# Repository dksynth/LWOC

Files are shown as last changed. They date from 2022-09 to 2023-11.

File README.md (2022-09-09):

# LWOC
Ornament and Crime for Loudest Warning Format

please note that there are two different spacings in use. 

The "broken grid" variant pushes two rows a bit closer together towards the screen at the bottom. This preserves the spacing of the top row at the cost of a crowded set of jacks nearer the encoders and  screen. 

IN ALMOST ALL CASES (unless you've made your own panels) you will want to use the main files found in the main repository.

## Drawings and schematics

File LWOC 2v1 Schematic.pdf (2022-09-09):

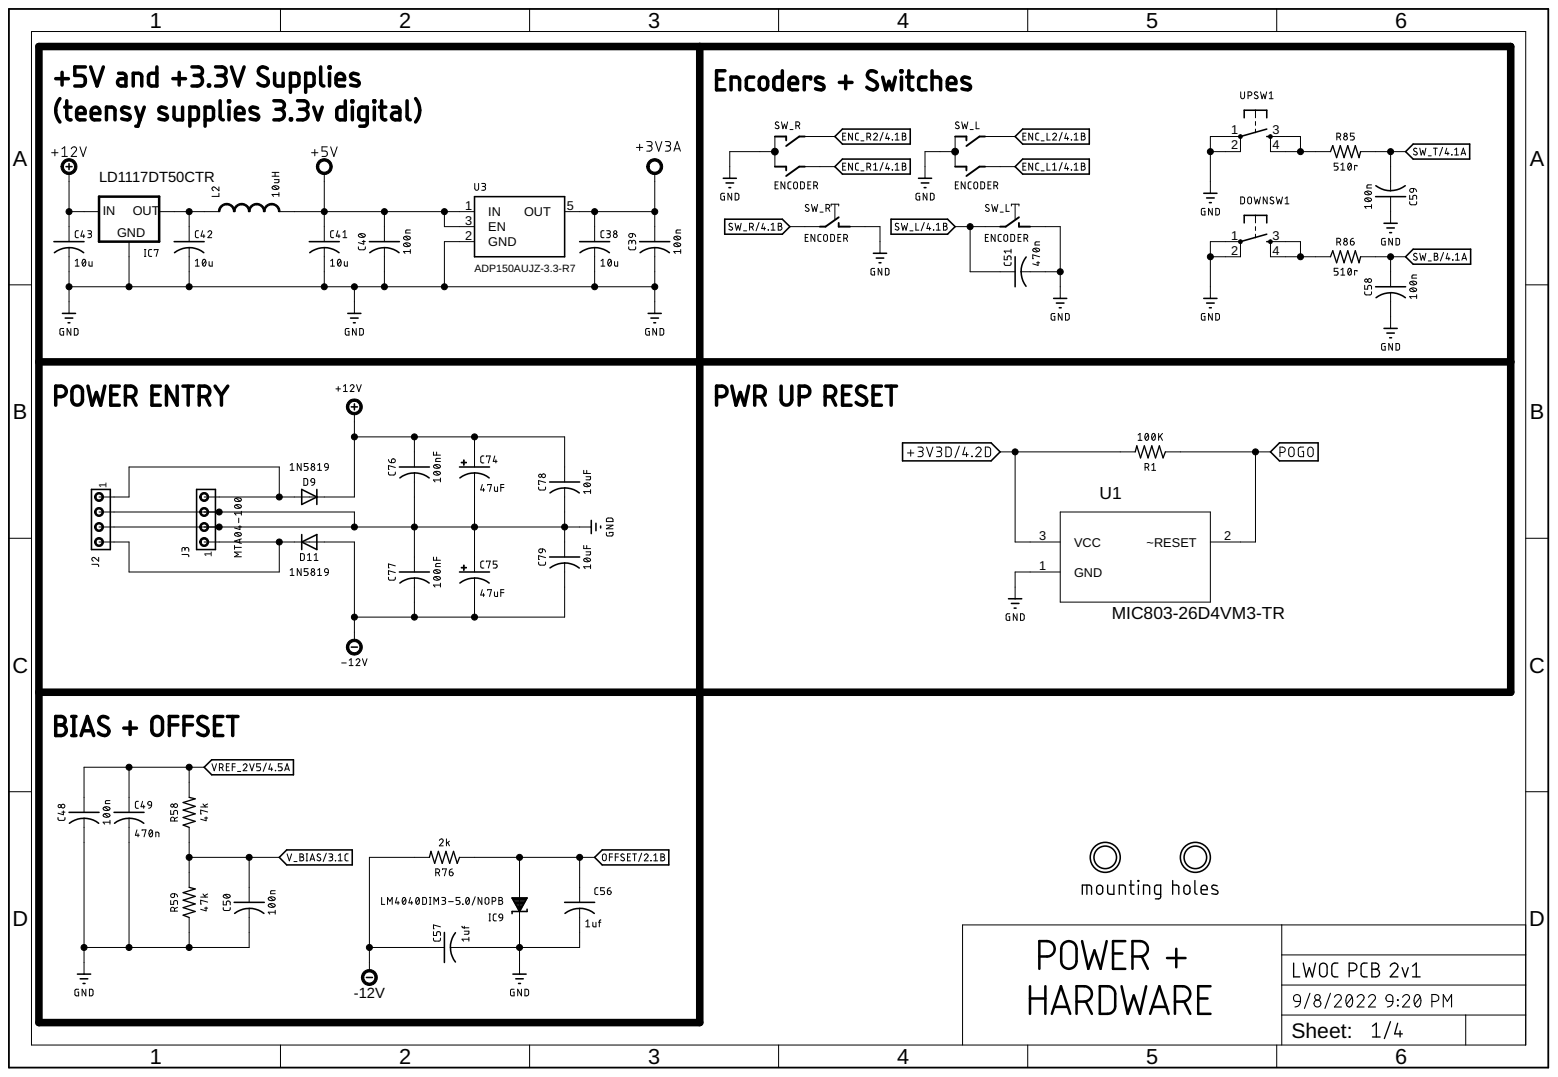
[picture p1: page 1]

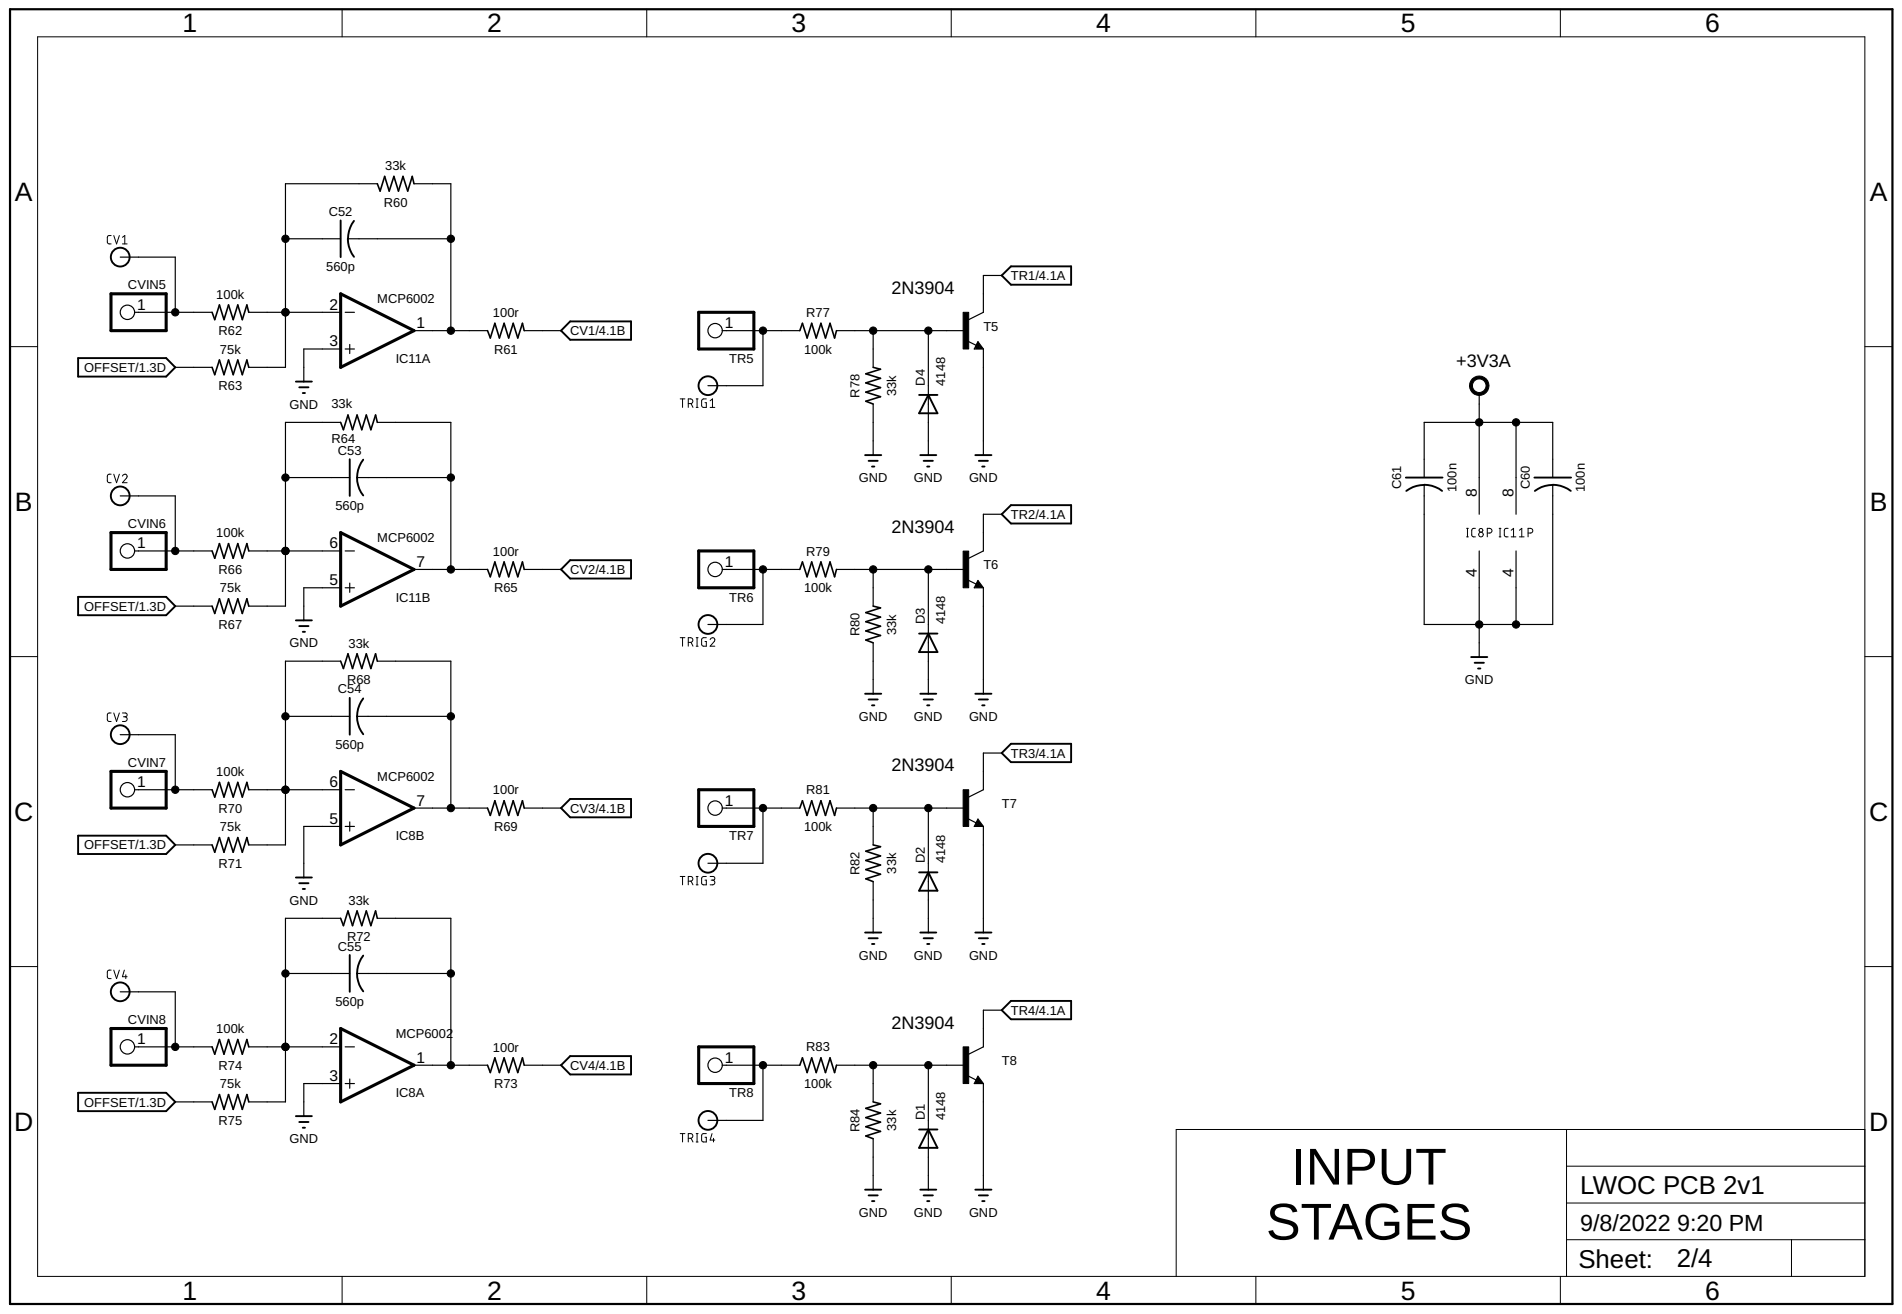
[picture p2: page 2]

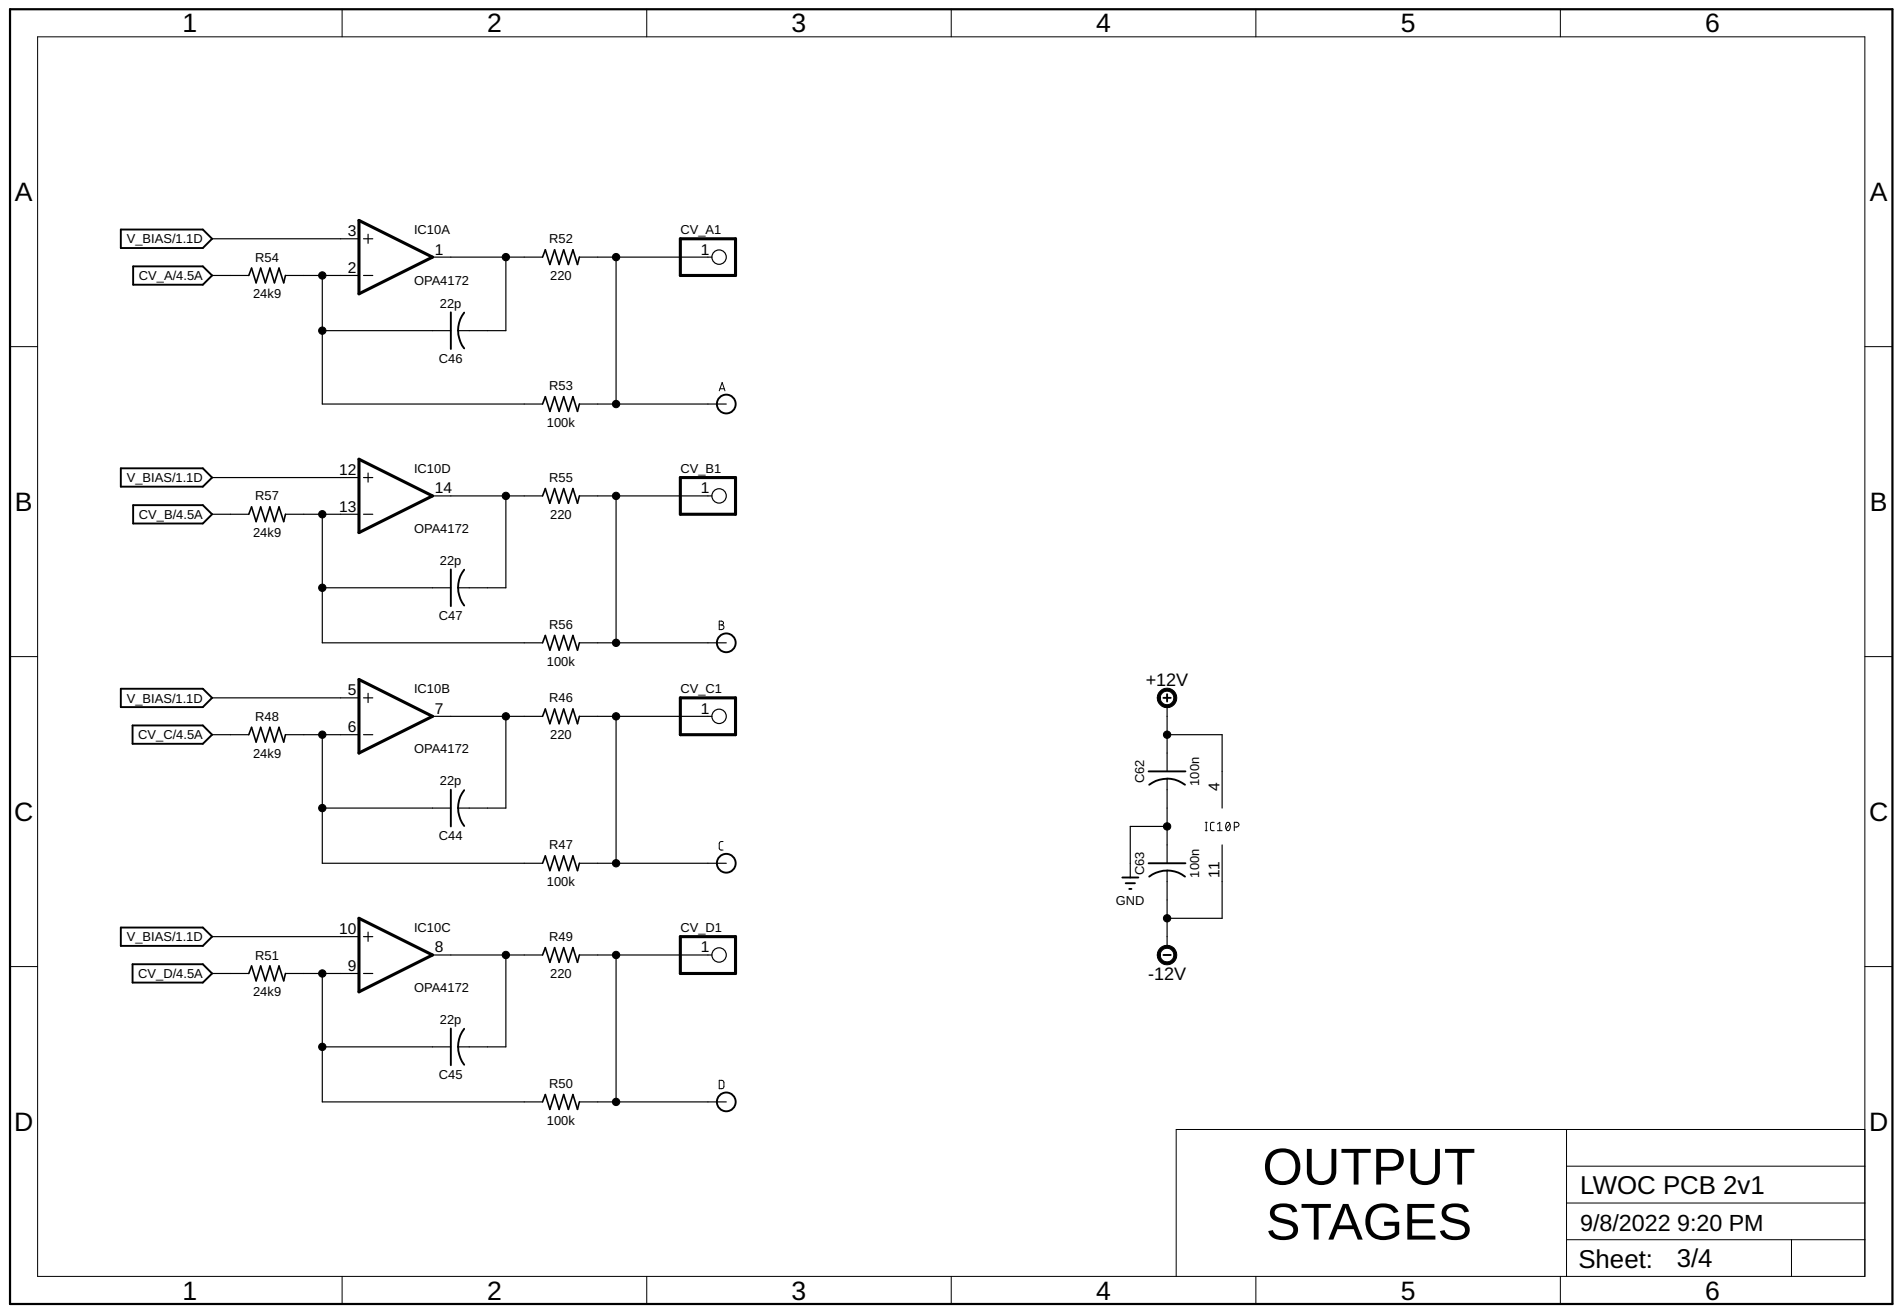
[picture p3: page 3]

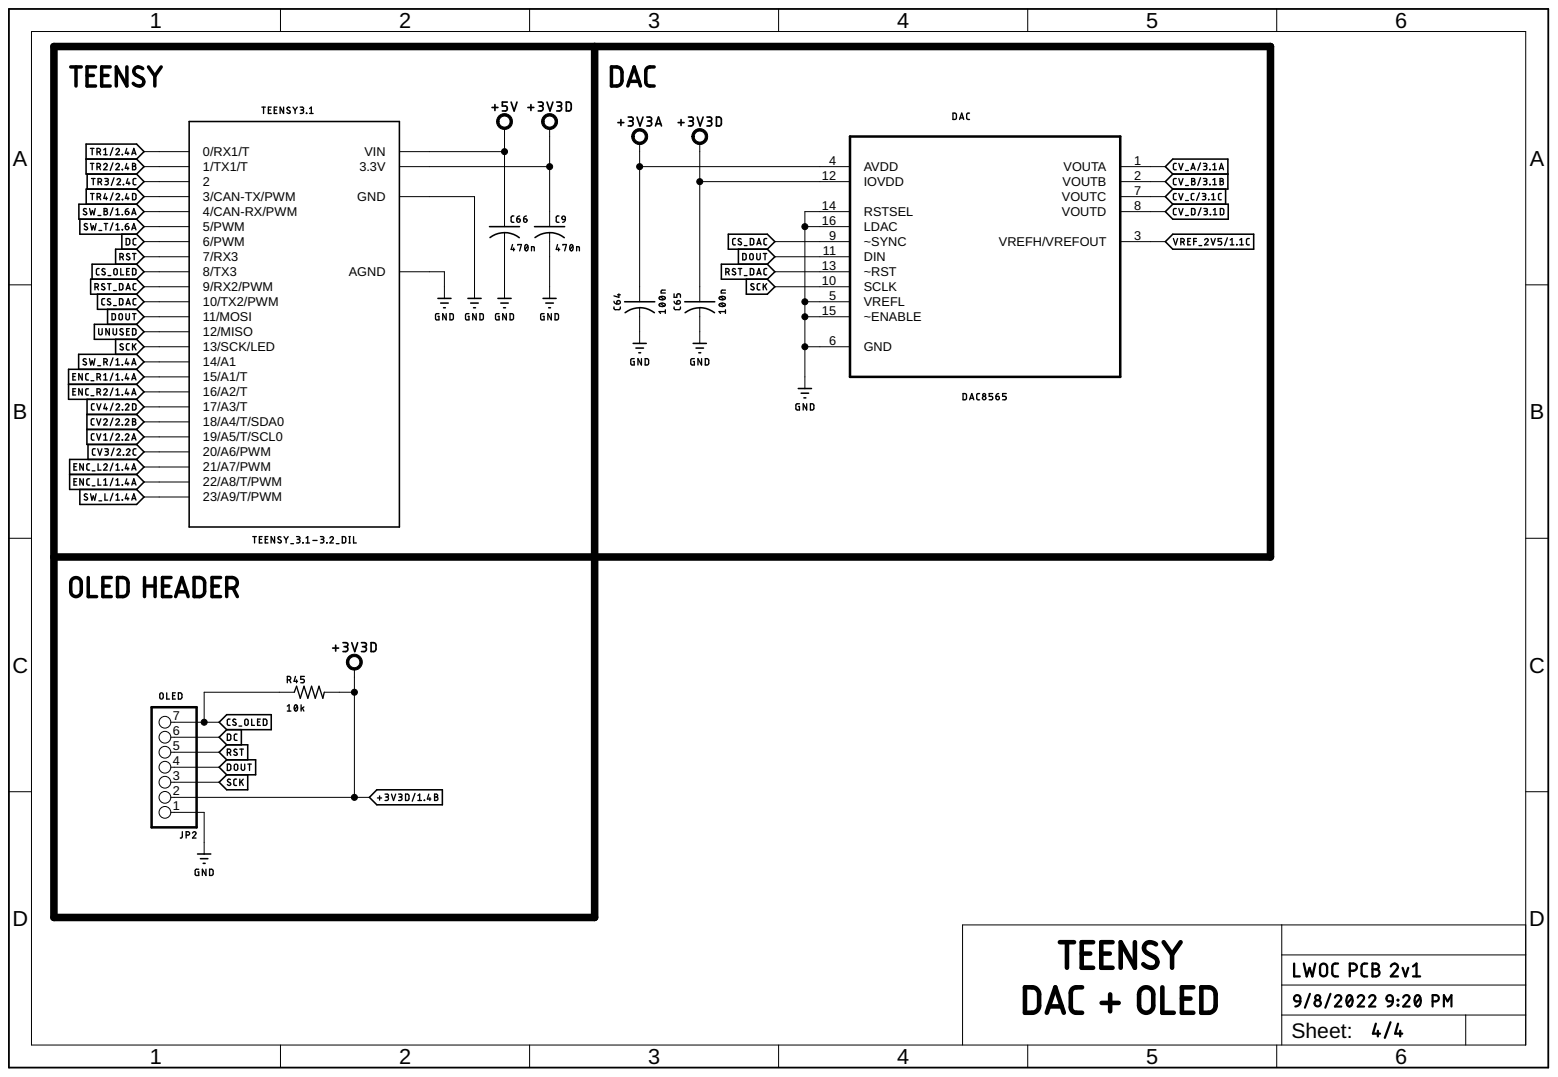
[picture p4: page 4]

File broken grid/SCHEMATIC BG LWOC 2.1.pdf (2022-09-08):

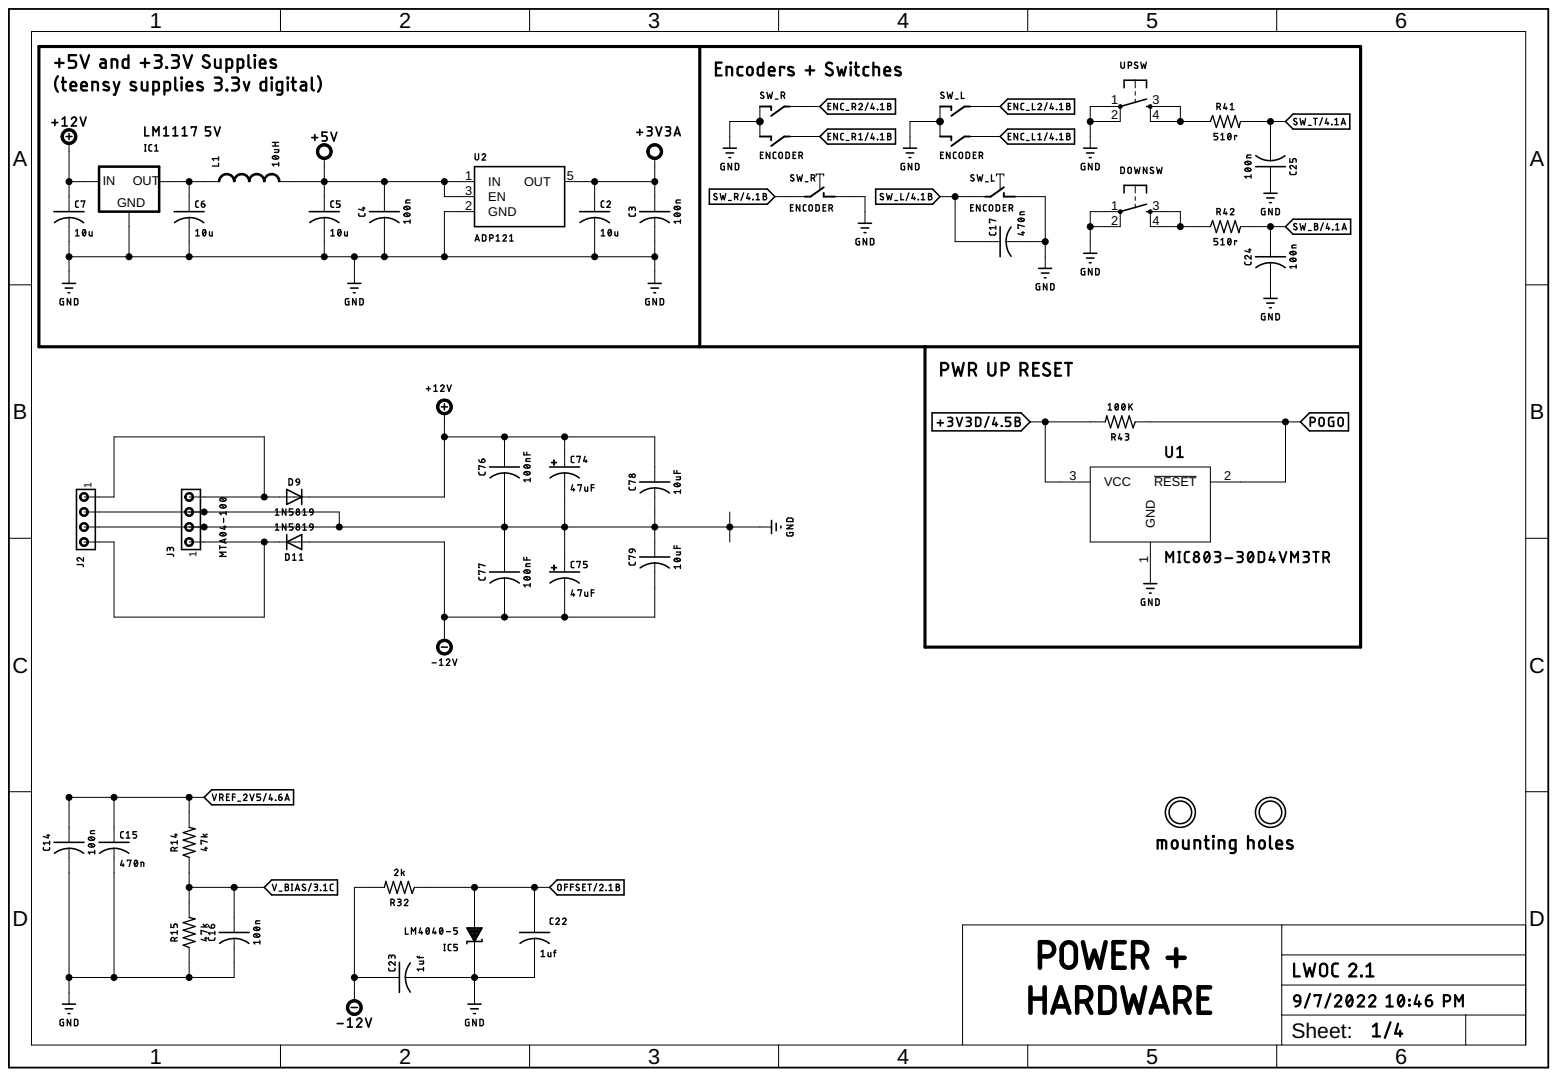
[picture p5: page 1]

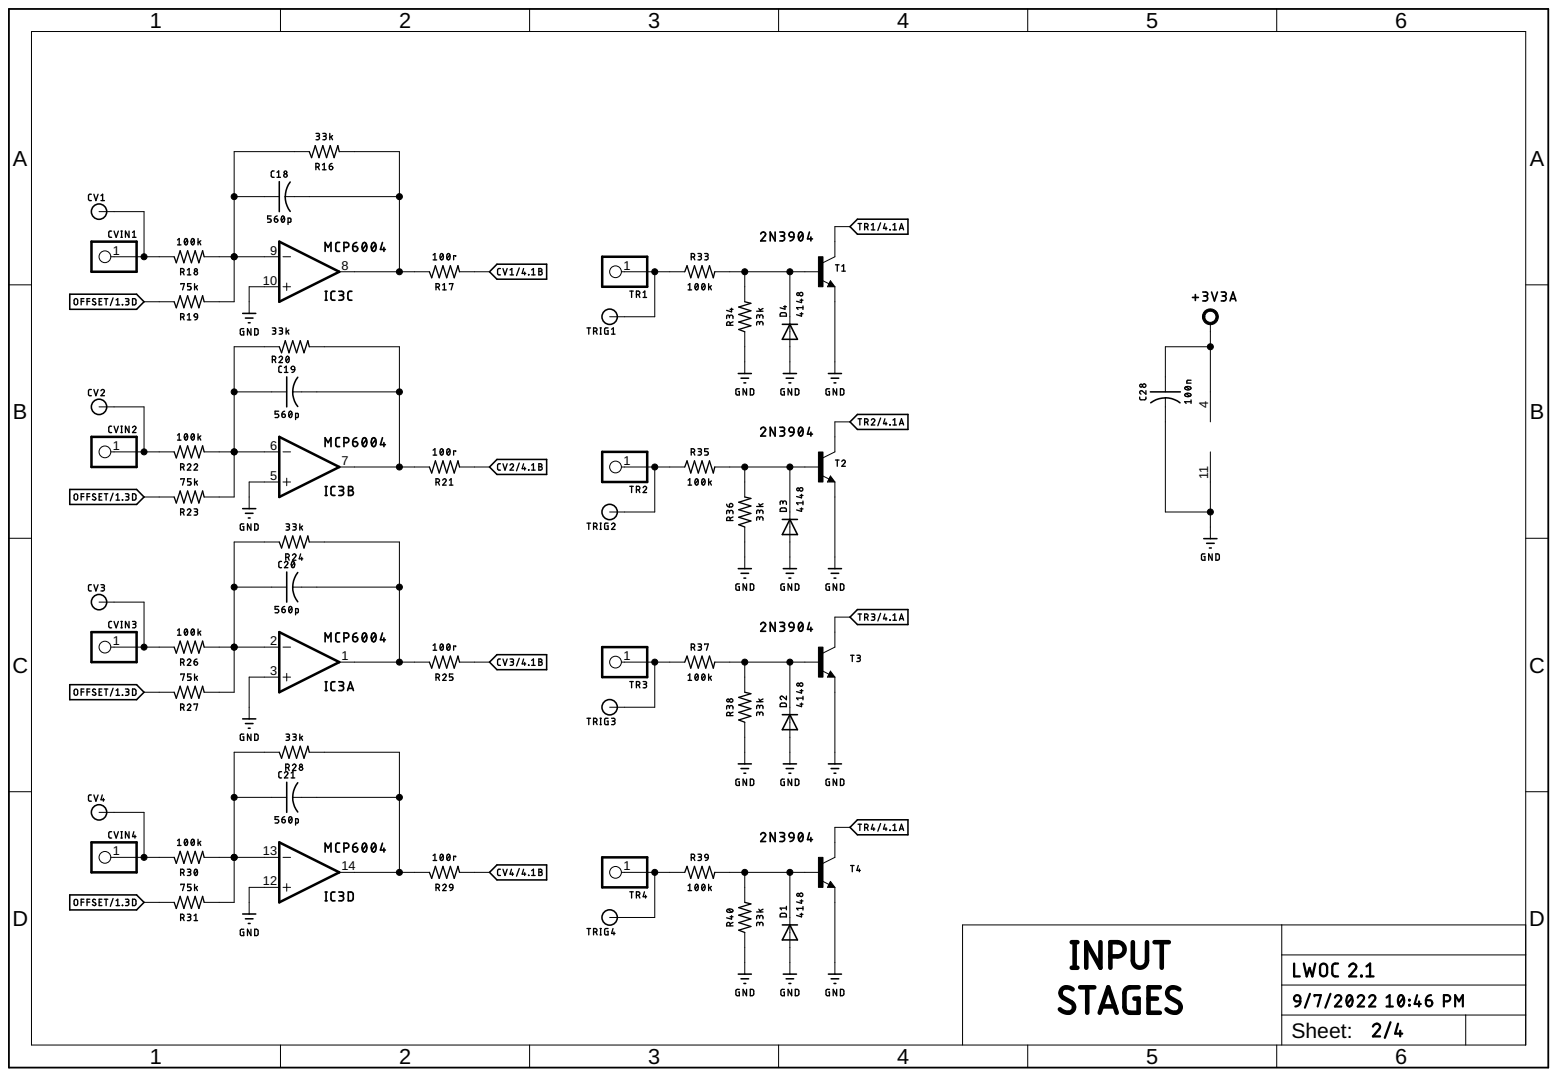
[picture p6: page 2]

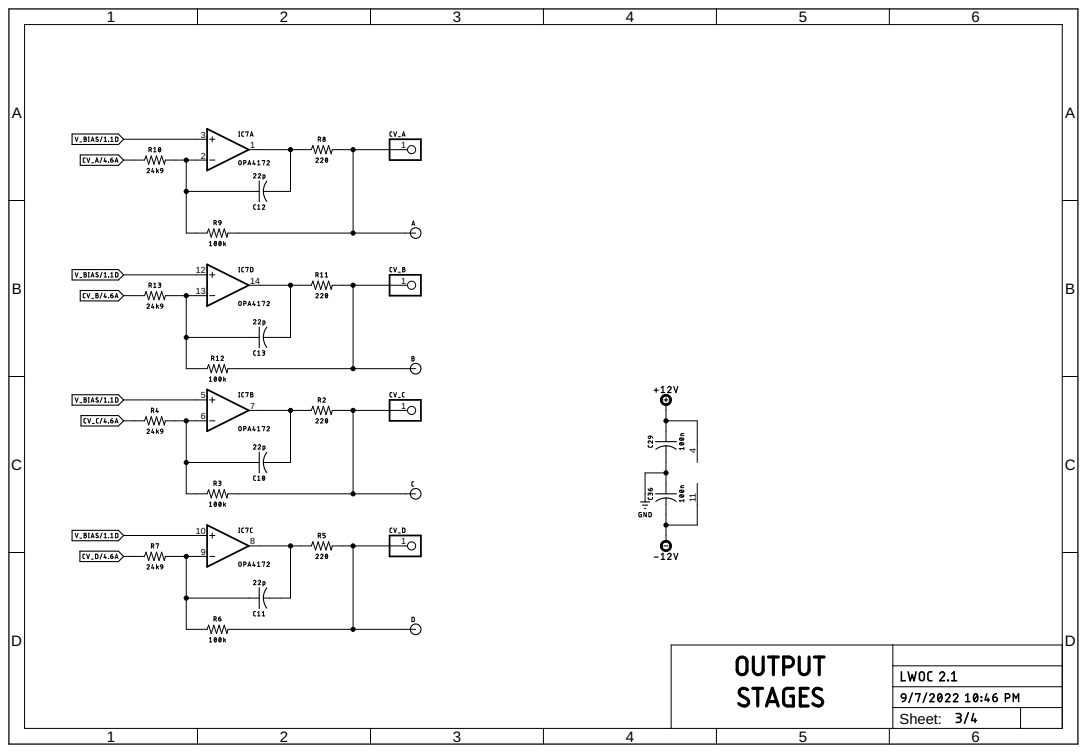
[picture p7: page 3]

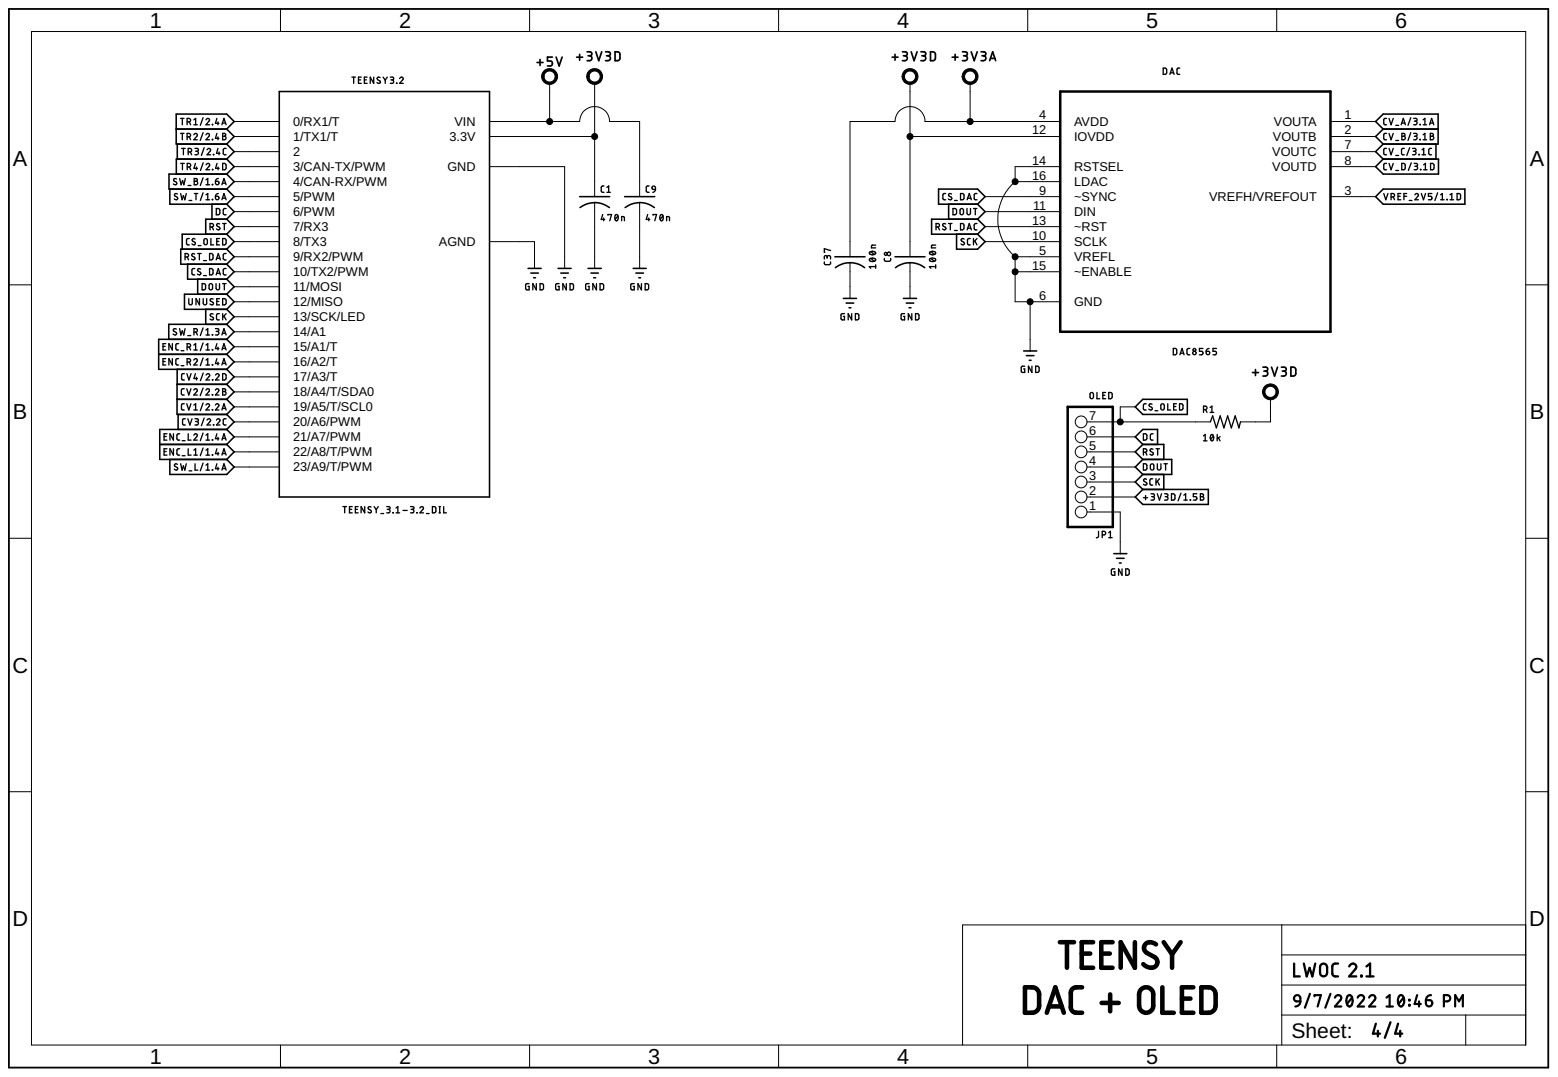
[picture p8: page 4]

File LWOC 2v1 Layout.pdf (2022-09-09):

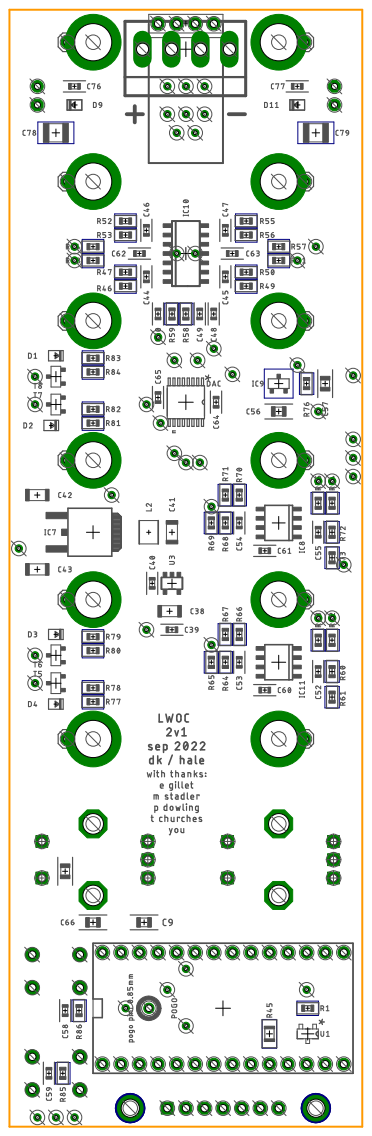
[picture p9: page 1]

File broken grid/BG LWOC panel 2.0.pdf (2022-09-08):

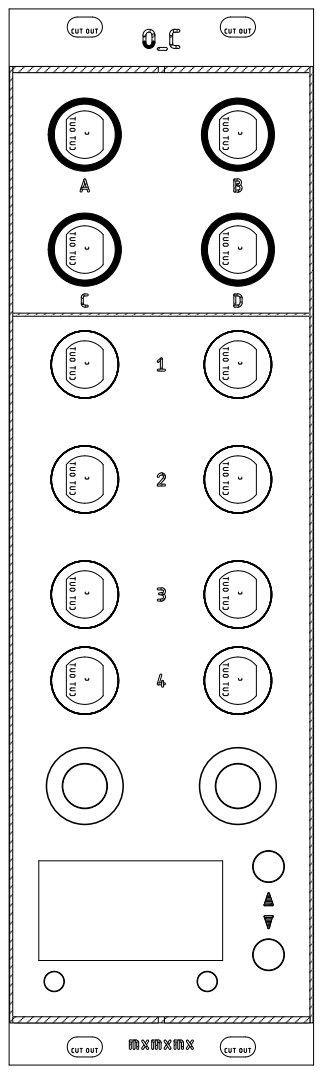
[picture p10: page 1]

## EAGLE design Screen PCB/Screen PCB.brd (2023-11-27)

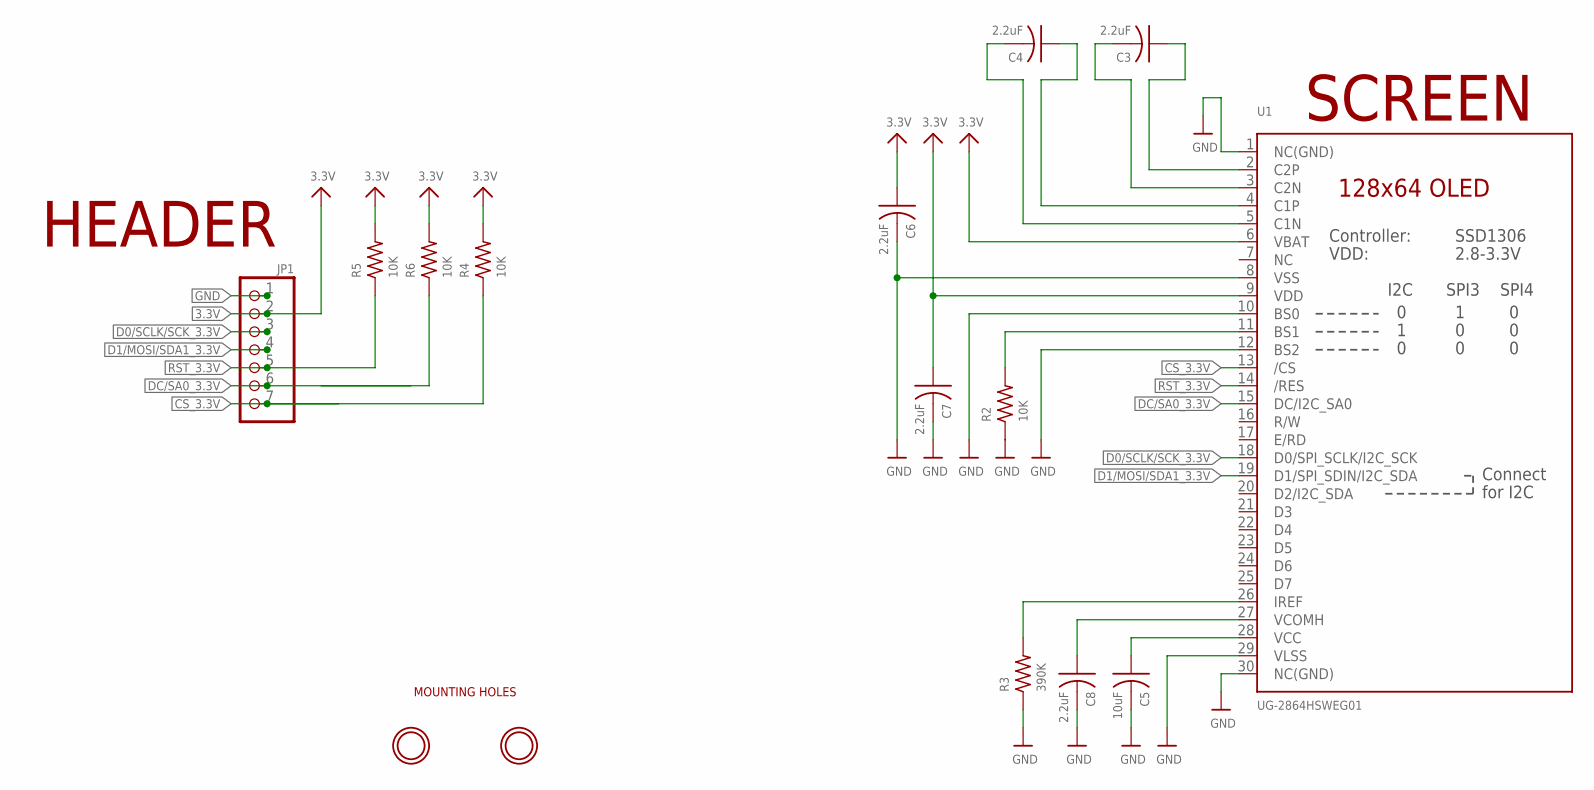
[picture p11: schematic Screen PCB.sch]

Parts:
C3, C4, C6, C7, C8: 2.2uF; C0805
C5: 10uF; C0805
JP1: HEADER-1X7ROUND; 1X07_ROUND
R2, R4, R5, R6: 10K; R0805
R3: 390K; R0805
U1: UG-2864HSWEG01; UG-2864HSWEG01_1.3_WRAPAROUND
U$23, U$26: MOUNTINGHOLE2.5; MOUNTINGHOLE_2.5_PLATED

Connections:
3.3V: C6.1, C7.1, JP1.2, R4.2, R5.2, R6.2, U1.6 (VBAT), U1.9 (VDD)
CS_3.3V: JP1.7, R4.1, U1.13 (/CS)
D0/SCLK/SCK_3.3V: JP1.3, U1.18 (D0/SPI_SCLK/I2C_SCK)
D1/MOSI/SDA1_3.3V: JP1.4, U1.19 (D1/SPI_SDIN/I2C_SDA)
DC/SA0_3.3V: JP1.6, R6.1, U1.15 (DC/I2C_SA0)
GND: C5.2, C6.2, C7.2, C8.2, JP1.1, R2.1, R3.1, U1.1 (NC(GND)), U1.8 (VSS), U1.10 (BS0), U1.12 (BS2), U1.29 (VLSS), U1.30 (NC(GND))
unnamed: R2.2, U1.11 (BS1)
unnamed: R3.2, U1.26 (IREF)
unnamed: C4.1, U1.4 (C1P)
unnamed: C3.2, U1.3 (C2N)
unnamed: C3.1, U1.2 (C2P)
unnamed: C4.2, U1.5 (C1N)
unnamed: C5.1, U1.28 (VCC)
unnamed: C8.1, U1.27 (VCOMH)
RST_3.3V: JP1.5, R5.1, U1.14 (/RES)

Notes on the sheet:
MOUNTING HOLES
SCREEN
HEADER

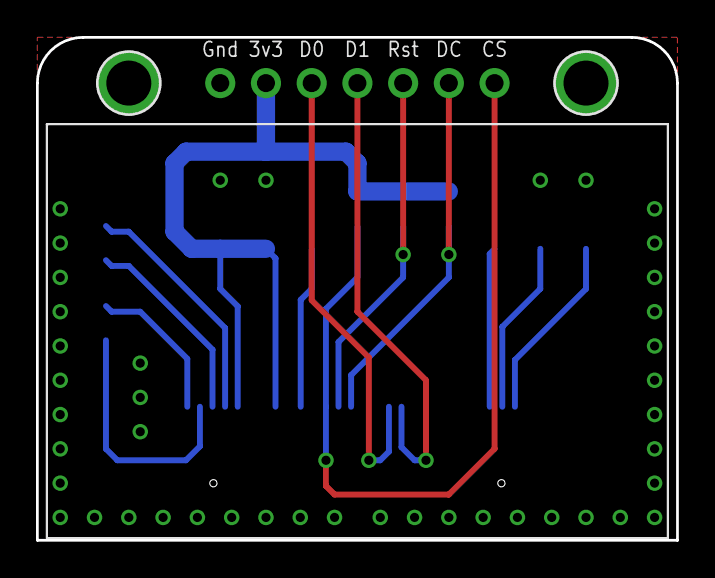
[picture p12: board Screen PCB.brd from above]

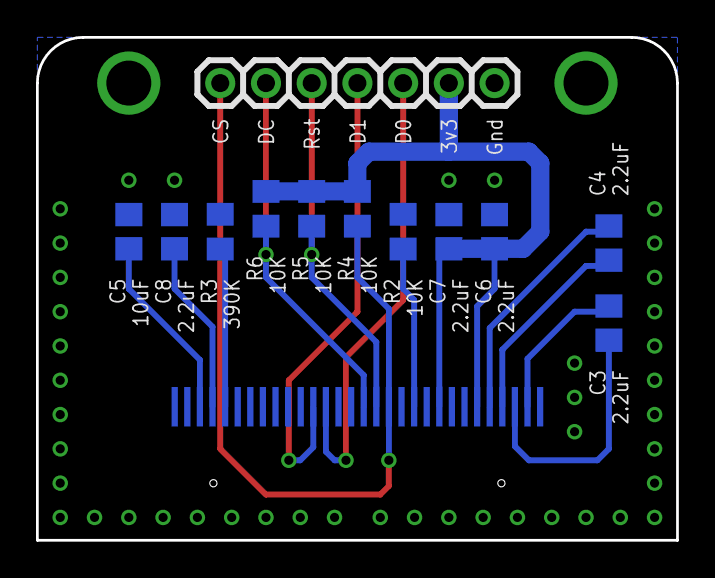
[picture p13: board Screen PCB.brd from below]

Board: 2 copper layers, 35.6 x 27.9 mm, 15 parts (11 on the bottom side), 15 nets.

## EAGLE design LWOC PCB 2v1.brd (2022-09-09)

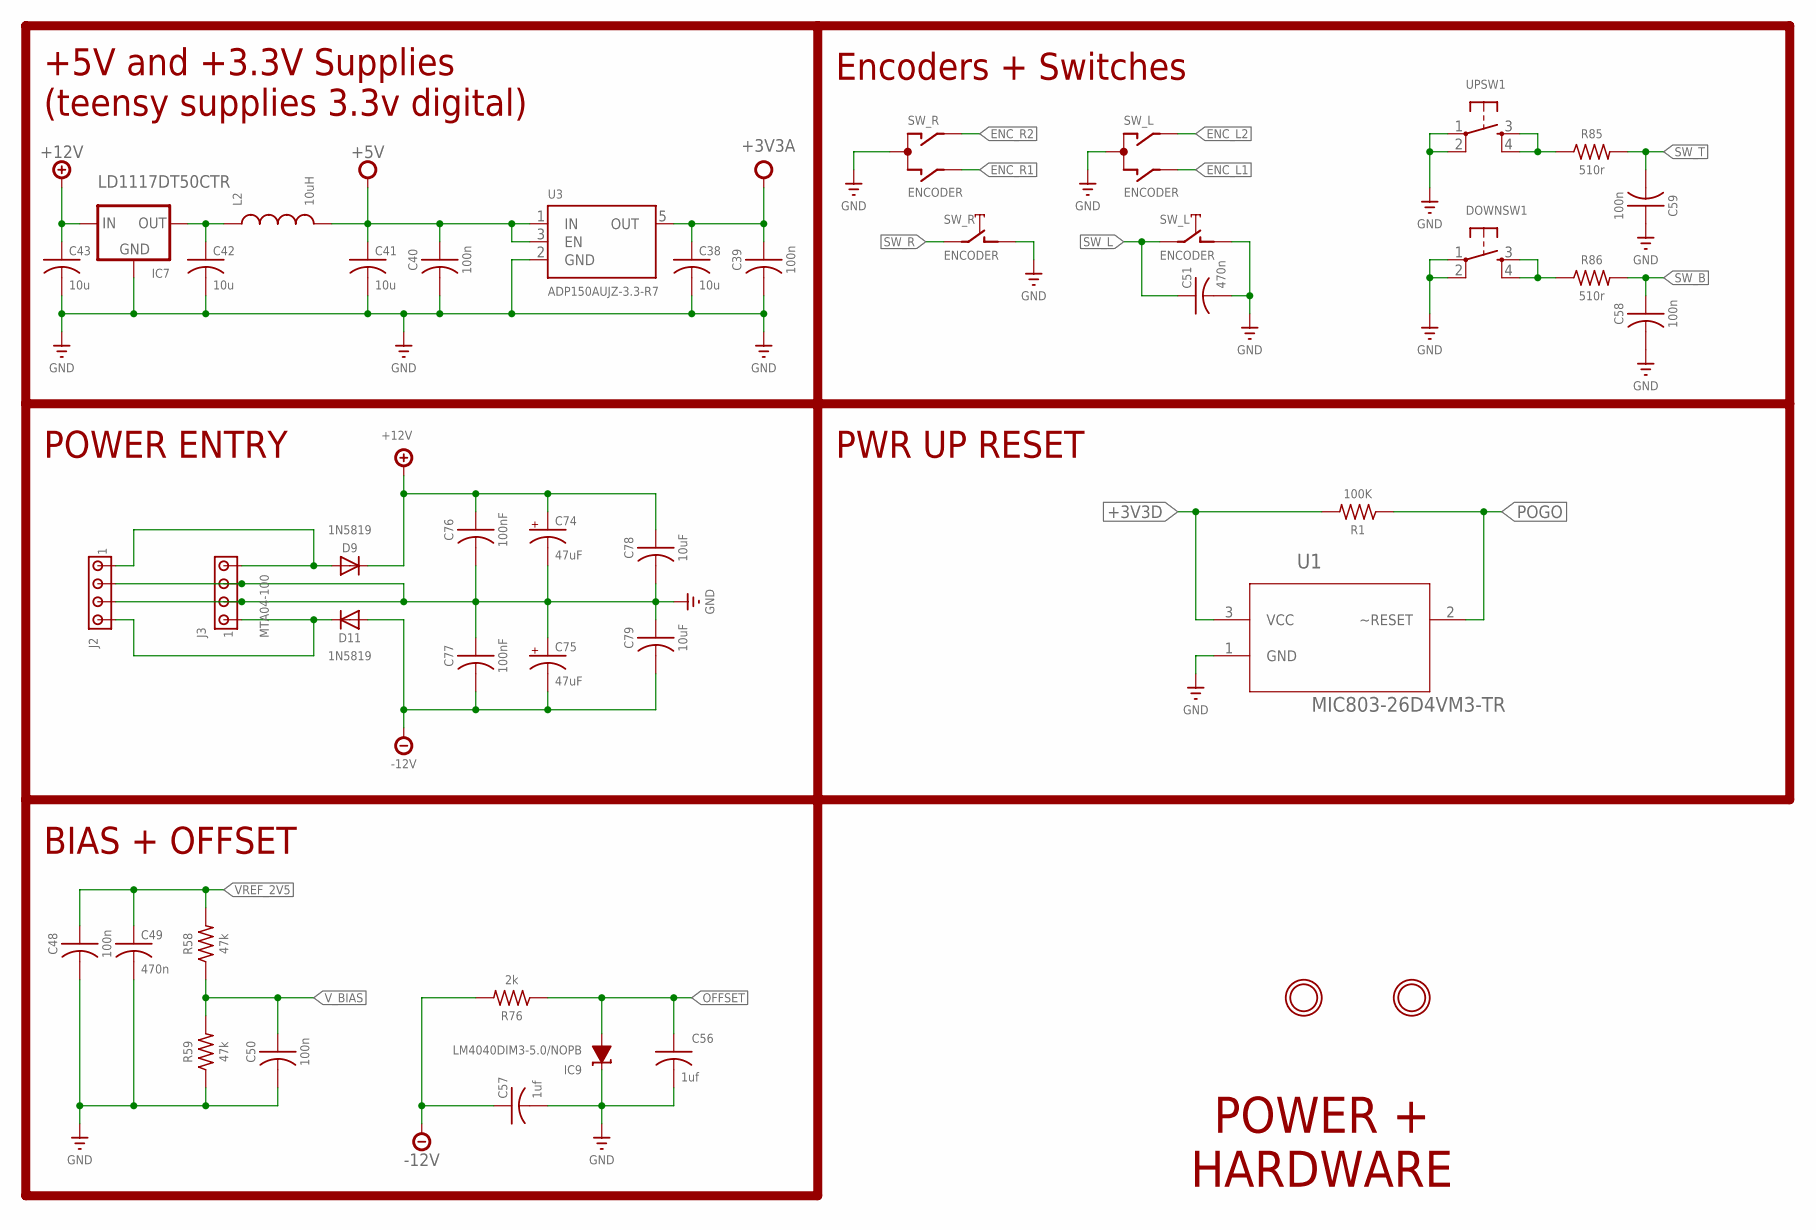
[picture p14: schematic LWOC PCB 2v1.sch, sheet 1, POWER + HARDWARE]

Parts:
C38, C41, C42, C43: 10u; C1206K
C39, C40, C48, C50, C58, C59: 100n; RCL_C0603K
C49: 470n; RCL_C0603K
C51: 470n; C0805K
C56, C57: 1uf; C0805K
C74, C75: 47uF; RCL_E2,5-6
C76, C77: 100nF; RCL_C0603K
C78, C79: 10uF; RCL_C1210
D9, D11: 1N5819; DIODE_SOD323-W
DOWNSW1: SPARKFUN_TAC_SWITCHPTH; SPARKFUN_TACTILE-PTH
IC7: LD1117DT50CTR; TO252
IC9: LM4040DIM3-5.0/NOPB; DBZ_R-PDSO-G3
J2: MTA04-156; 1X4MTA
J3: MTA04-100; 1X04MTA
L2: 10uH; 1210
R1: 100K; RCL_R0603
R58, R59: 47k; RCL_R0603
R76: 2k; RCL_R0603
R85, R86: 510r; RCL_R0603
SW_L: ENCODER; OG-ENCODER_ALPS_EC12E_SW
SW_R: ENCODER; OG-ENCODER_ALPS_EC12E_SW
U1: MIC803-26D4VM3-TR; SOT95P232X110-3N
U3: ADP150AUJZ-3.3-R7; SOT23-5
U$23, U$26: MOUNTINGHOLE2.5; MOUNTINGHOLE_2.5_PLATED
UPSW1: SPARKFUN_TAC_SWITCHPTH; SPARKFUN_TACTILE-PTH

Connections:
+3V3A: C38.1, C39.1, U3.5 (OUT); also elsewhere on the board
+3V3D: R1.2, U1.3 (VCC); also elsewhere on the board
+5V: C40.1, C41.1, L2.2, U3.1 (IN), U3.3 (EN); also elsewhere on the board
+12V: C43.1, C74.+, C76.1, C78.1, D9.C, IC7.2 (IN); also elsewhere on the board
-12V: C57.1, C75.-, C77.2, C79.2, D11.A, R76.2; also elsewhere on the board
ENC_L1: SW_L.B; also elsewhere on the board
ENC_L2: SW_L.A; also elsewhere on the board
ENC_R1: SW_R.B; also elsewhere on the board
ENC_R2: SW_R.A; also elsewhere on the board
GND: C38.2, C39.2, C40.2, C41.2, C42.2, C43.2, C48.2, C49.2, C50.2, C51.2, C56.2, C57.2, C58.2, C59.1, C74.-, C75.+, C76.2, C77.1, C78.2, C79.1, DOWNSW1.1, DOWNSW1.2, IC7.1 (GND), IC9.1 (C), J2.2, J2.3, J3.2 (3), J3.3 (2), R59.1, SW_L.C, SW_L.D (1), SW_R.C, SW_R.D (1), U1.1 (GND), U3.2 (GND), UPSW1.1, UPSW1.2; also elsewhere on the board
unnamed: C42.1, IC7.3 (OUT), L2.1
unnamed: R85.1, UPSW1.3, UPSW1.4
unnamed: DOWNSW1.3, DOWNSW1.4, R86.1
unnamed: D11.C, J2.4, J3.4 (1)
unnamed: D9.A, J2.1, J3.1 (4)
OFFSET: C56.1, IC9.2 (A), R76.1; also elsewhere on the board
POGO: R1.1, U1.2 (~RESET)
SW_B: C58.1, R86.2; also elsewhere on the board
SW_L: C51.1, SW_L.E (2); also elsewhere on the board
SW_R: SW_R.E (2); also elsewhere on the board
SW_T: C59.2, R85.2; also elsewhere on the board
VREF_2V5: C48.1, C49.1, R58.2; also elsewhere on the board
V_BIAS: C50.1, R58.1, R59.2; also elsewhere on the board

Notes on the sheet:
POWER + HARDWARE
+5V and +3.3V Supplies (teensy supplies 3.3v digital)
Encoders + Switches
PWR UP RESET
POWER ENTRY
BIAS + OFFSET

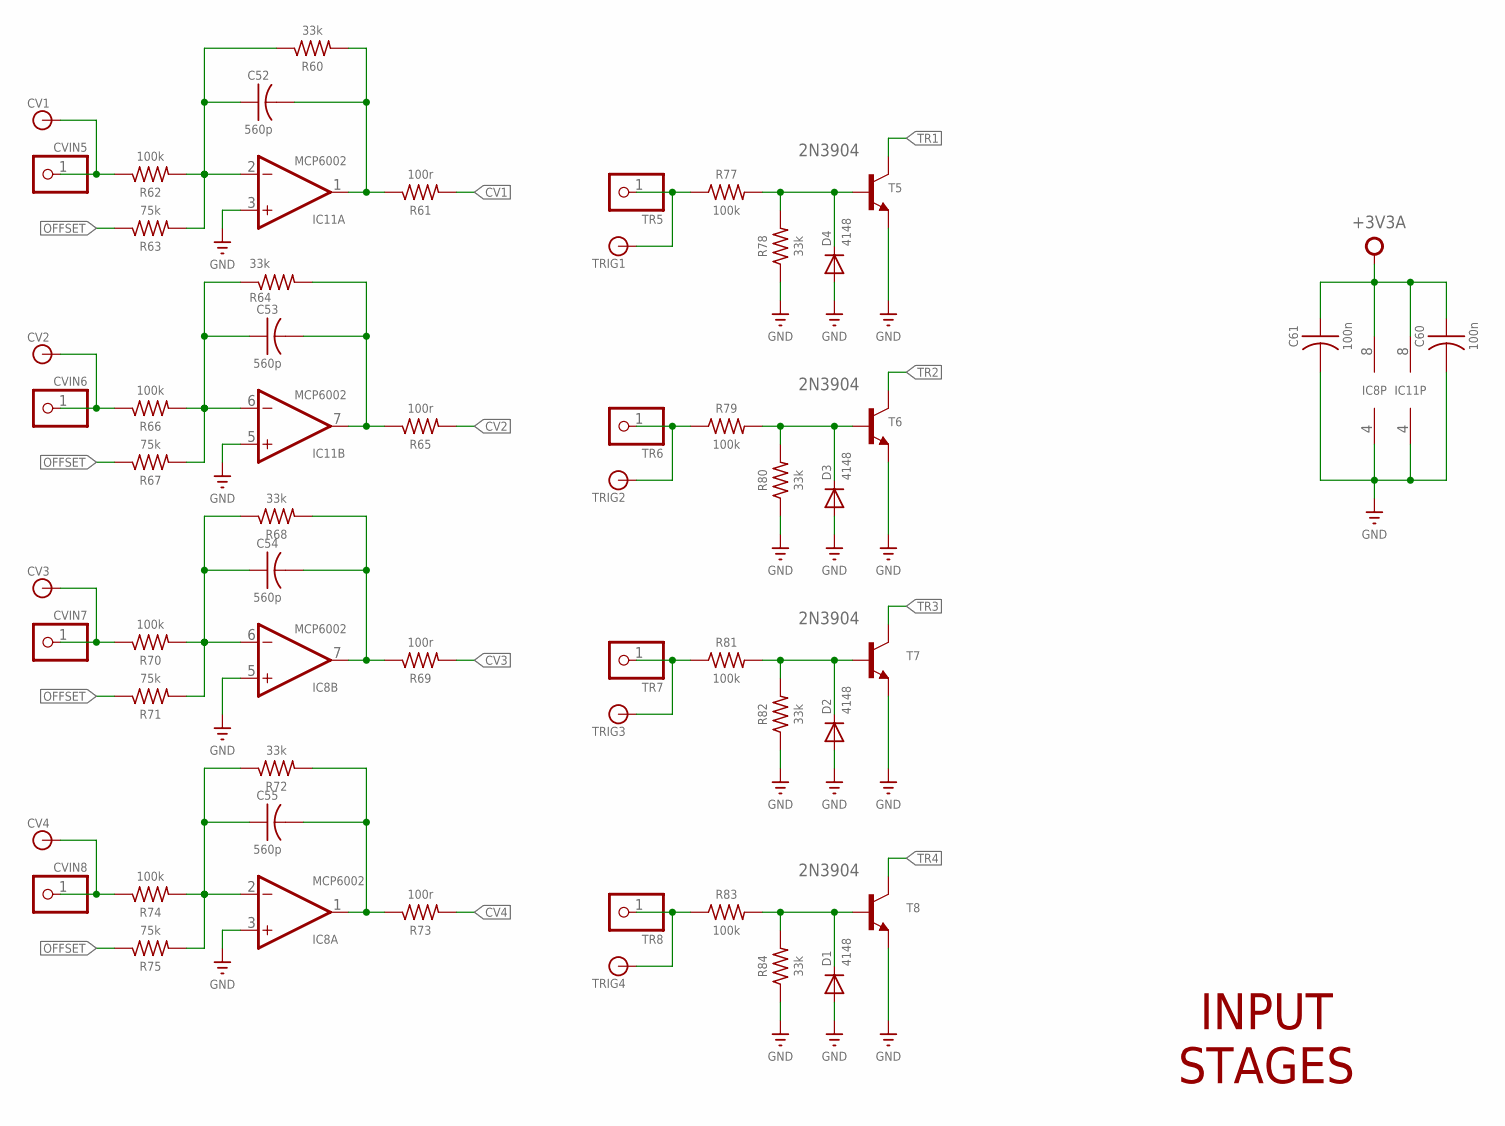
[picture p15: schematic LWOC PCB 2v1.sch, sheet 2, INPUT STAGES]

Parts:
C52, C53, C54, C55: 560p; RCL_C0603K
C60, C61: 100n; RCL_C0603K
CV1, CV2, CV3, CV4: BANANA_CONN
CVIN5, CVIN6, CVIN7, CVIN8: PINHD-1X1; 1X01
D1, D2, D3, D4: 4148; DIODE_SOD323-W
IC8, IC11: MCP6002; GM-ICS_SO08
R60, R64, R68, R72, R78, R80, R82, R84: 33k; RCL_R0603
R61, R65, R69, R73: 100r; RCL_R0603
R62, R66, R70, R74, R77, R79, R81, R83: 100k; RCL_R0603
R63, R67, R71, R75: 75k; RCL_R0603
T5, T6, T7, T8: 2N3904; TRANSISTOR_SOT23-BEC
TR5, TR6, TR7, TR8: PINHD-1X1; 1X01
TRIG1, TRIG2, TRIG3, TRIG4: BANANA_CONN

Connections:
+3V3A: C60.1, C61.1, IC8.8 (V+), IC11.8 (V+); also elsewhere on the board
CV1: R61.2; also elsewhere on the board
CV2: R65.2; also elsewhere on the board
CV3: R69.2; also elsewhere on the board
CV4: R73.2; also elsewhere on the board
GND: C60.2, C61.2, D1.A, D2.A, D3.A, D4.A, IC8.3 (+IN), IC8.4 (V-), IC8.5 (+IN), IC11.3 (+IN), IC11.4 (V-), IC11.5 (+IN), R78.1, R80.1, R82.1, R84.1, T5.E, T6.E, T7.E, T8.E; also elsewhere on the board
unnamed: CV1.P$1, CVIN5.1, R62.1
unnamed: C52.1, IC11.2 (-IN), R60.1, R62.2, R63.2
unnamed: C52.2, IC11.1 (OUT), R60.2, R61.1
unnamed: CV2.P$1, CVIN6.1, R66.1
unnamed: C53.1, IC11.6 (-IN), R64.1, R66.2, R67.2
unnamed: C53.2, IC11.7 (OUT), R64.2, R65.1
unnamed: CV3.P$1, CVIN7.1, R70.1
unnamed: C54.1, IC8.6 (-IN), R68.1, R70.2, R71.2
unnamed: C54.2, IC8.7 (OUT), R68.2, R69.1
unnamed: CV4.P$1, CVIN8.1, R74.1
unnamed: C55.1, IC8.2 (-IN), R72.1, R74.2, R75.2
unnamed: C55.2, IC8.1 (OUT), R72.2, R73.1
unnamed: R77.1, TR5.1, TRIG1.P$1
unnamed: R79.1, TR6.1, TRIG2.P$1
unnamed: R81.1, TR7.1, TRIG3.P$1
unnamed: D1.C, R83.2, R84.2, T8.B
unnamed: D2.C, R81.2, R82.2, T7.B
unnamed: D3.C, R79.2, R80.2, T6.B
unnamed: D4.C, R77.2, R78.2, T5.B
unnamed: R83.1, TR8.1, TRIG4.P$1
OFFSET: R63.1, R67.1, R71.1, R75.1; also elsewhere on the board
TR1: T5.C; also elsewhere on the board
TR2: T6.C; also elsewhere on the board
TR3: T7.C; also elsewhere on the board
TR4: T8.C; also elsewhere on the board

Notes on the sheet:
INPUT STAGES

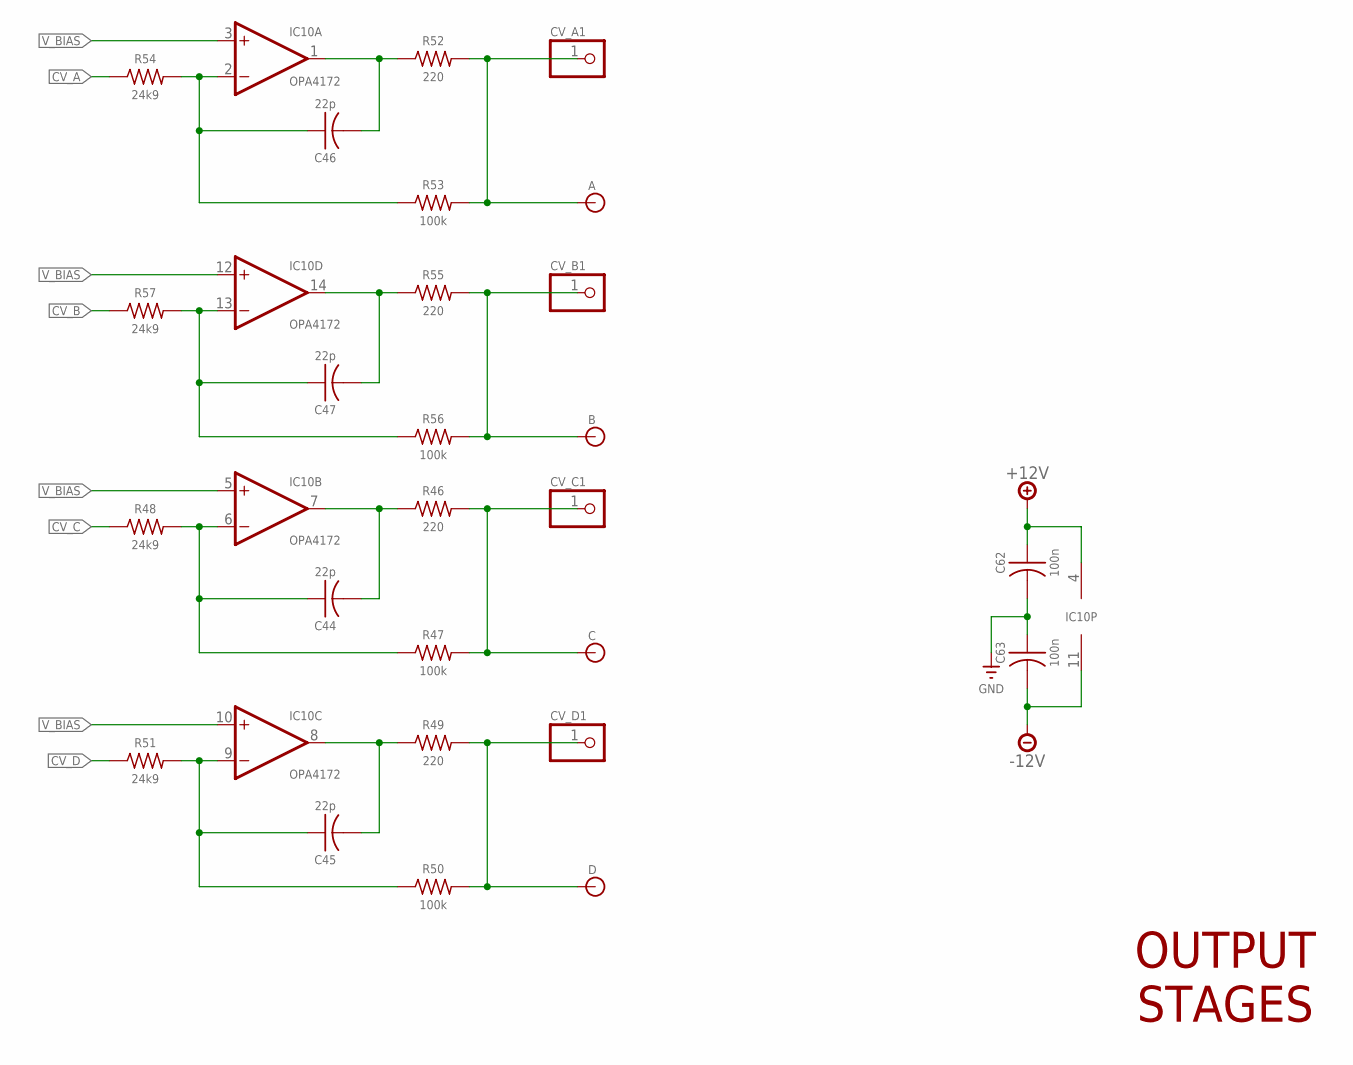
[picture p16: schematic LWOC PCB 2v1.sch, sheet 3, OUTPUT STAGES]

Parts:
A: BANANA_CONN
B: BANANA_CONN
C: BANANA_CONN
C44, C45, C46, C47: 22p; RCL_C0603K
C62, C63: 100n; RCL_C0603K
CV_A1: PINHD-1X1; 1X01
CV_B1: PINHD-1X1; 1X01
CV_C1: PINHD-1X1; 1X01
CV_D1: PINHD-1X1; 1X01
D: BANANA_CONN
IC10: OPA4172; GM-ICS_SO14
R46, R49, R52, R55: 220; RCL_R0603
R47, R50, R53, R56: 100k; RCL_R0603
R48, R51, R54, R57: 24k9; RCL_R0603

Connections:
+12V: C62.1, IC10.4 (V+); also elsewhere on the board
-12V: C63.2, IC10.11 (V-); also elsewhere on the board
CV_A: R54.1; also elsewhere on the board
CV_B: R57.1; also elsewhere on the board
CV_C: R48.1; also elsewhere on the board
CV_D: R51.1; also elsewhere on the board
GND: C62.2, C63.1; also elsewhere on the board
unnamed: C44.1, IC10.6 (-IN), R47.1, R48.2
unnamed: C44.2, IC10.7 (OUT), R46.1
unnamed: C45.1, IC10.9 (-IN), R50.1, R51.2
unnamed: C45.2, IC10.8 (OUT), R49.1
unnamed: C46.1, IC10.2 (-IN), R53.1, R54.2
unnamed: C46.2, IC10.1 (OUT), R52.1
unnamed: C47.1, IC10.13 (-IN), R56.1, R57.2
unnamed: C47.2, IC10.14 (OUT), R55.1
unnamed: B.P$1, CV_B1.1, R55.2, R56.2
unnamed: CV_D1.1, D.P$1, R49.2, R50.2
unnamed: A.P$1, CV_A1.1, R52.2, R53.2
unnamed: C.P$1, CV_C1.1, R46.2, R47.2
V_BIAS: IC10.3 (+IN), IC10.5 (+IN), IC10.10 (+IN), IC10.12 (+IN); also elsewhere on the board

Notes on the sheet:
OUTPUT STAGES

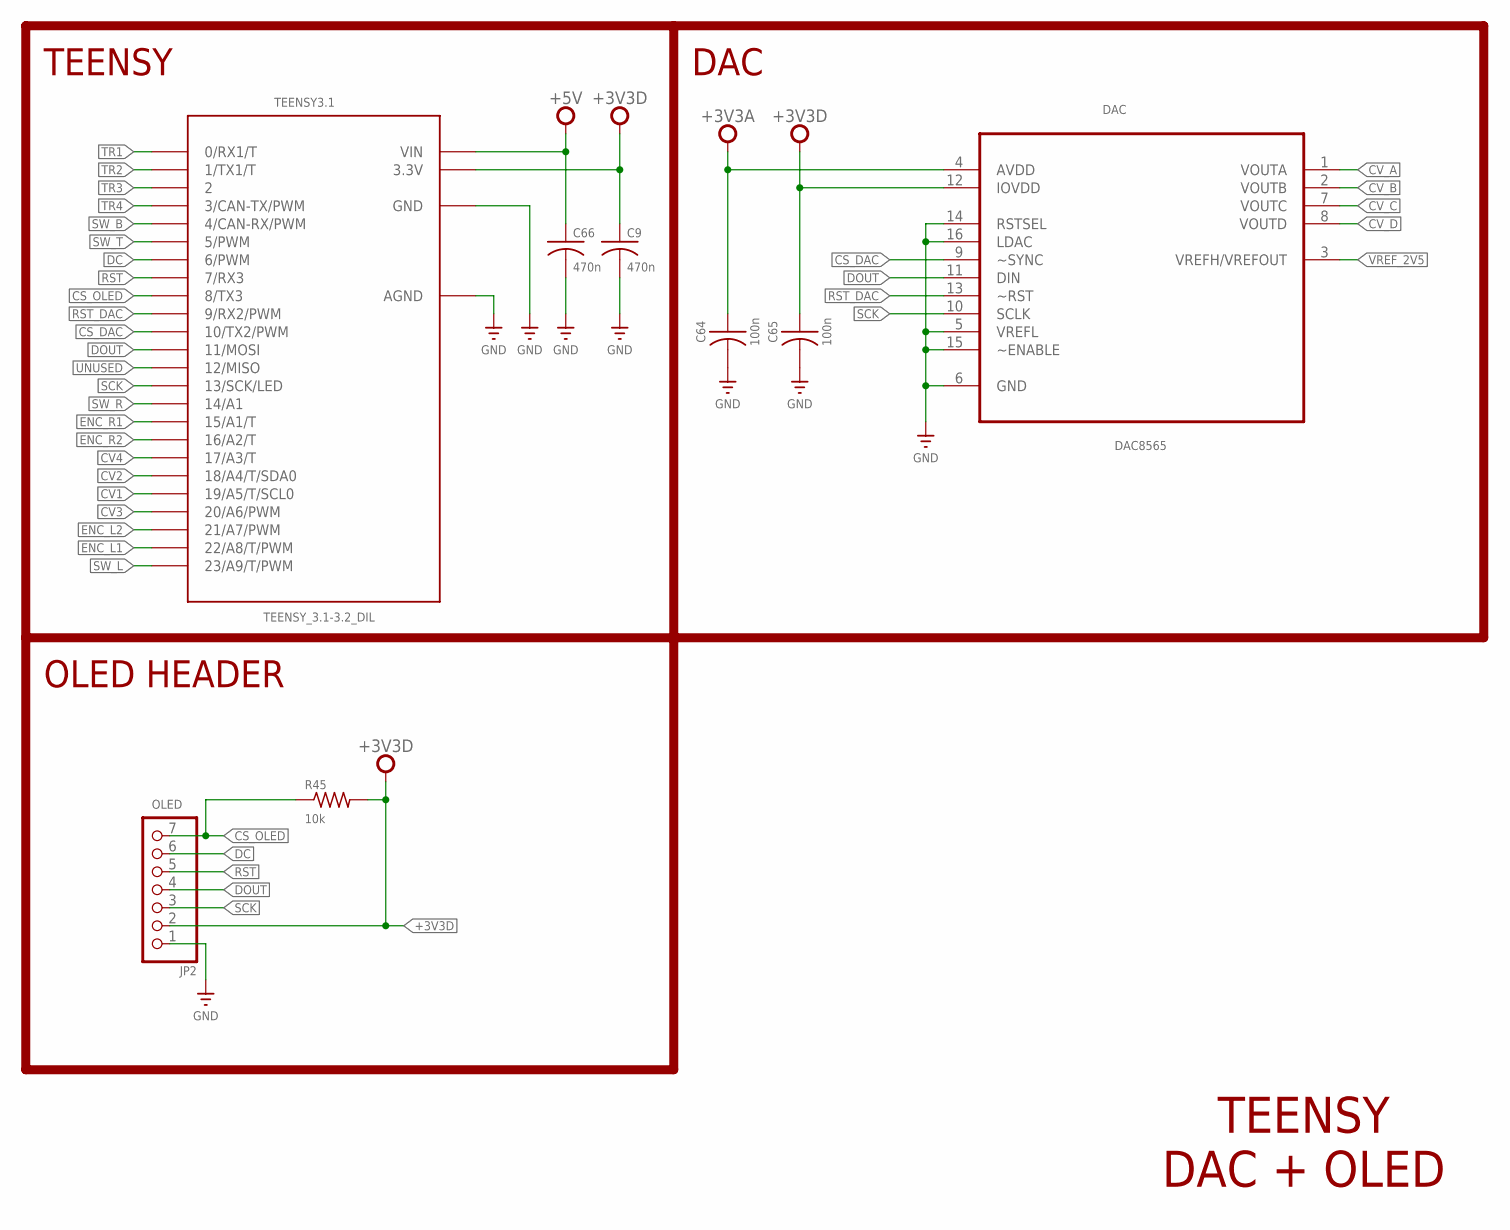
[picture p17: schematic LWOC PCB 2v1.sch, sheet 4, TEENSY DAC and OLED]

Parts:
C9, C66: 470n; C0805K
C64, C65: 100n; RCL_C0603K
DAC: DAC8565; SOP65P640X120-16N
JP2: OLED; 1X07-S
R45: 10k; M0805
TEENSY3.1: TEENSY_3.1-3.2_DIL; TEENSY_3.0-3.2&LC_DIL

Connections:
+3V3A: C64.1, DAC.4 (AVDD); also elsewhere on the board
+3V3D: C9.1, C65.1, DAC.12 (IOVDD), JP2.2, R45.2, TEENSY3.1.3.3V; also elsewhere on the board
+5V: C66.1, TEENSY3.1.VIN; also elsewhere on the board
CS_DAC: DAC.9 (~SYNC), TEENSY3.1.10 (10/TX2/PWM)
CS_OLED: JP2.7, R45.1, TEENSY3.1.8 (8/TX3)
CV1: TEENSY3.1.19/A5 (19/A5/T/SCL0); also elsewhere on the board
CV2: TEENSY3.1.18/A4 (18/A4/T/SDA0); also elsewhere on the board
CV3: TEENSY3.1.20/A6 (20/A6/PWM); also elsewhere on the board
CV4: TEENSY3.1.17/A3 (17/A3/T); also elsewhere on the board
CV_A: DAC.1 (VOUTA); also elsewhere on the board
CV_B: DAC.2 (VOUTB); also elsewhere on the board
CV_C: DAC.7 (VOUTC); also elsewhere on the board
CV_D: DAC.8 (VOUTD); also elsewhere on the board
DC: JP2.6, TEENSY3.1.6 (6/PWM)
DOUT: DAC.11 (DIN), JP2.4, TEENSY3.1.11 (11/MOSI)
ENC_L1: TEENSY3.1.22/A8 (22/A8/T/PWM); also elsewhere on the board
ENC_L2: TEENSY3.1.21/A7 (21/A7/PWM); also elsewhere on the board
ENC_R1: TEENSY3.1.15/A1 (15/A1/T); also elsewhere on the board
ENC_R2: TEENSY3.1.16/A2 (16/A2/T); also elsewhere on the board
GND: C9.2, C64.2, C65.2, C66.2, DAC.5 (VREFL), DAC.6 (GND), DAC.14 (RSTSEL), DAC.15 (~ENABLE), DAC.16 (LDAC), JP2.1, TEENSY3.1.AGND, TEENSY3.1.GND; also elsewhere on the board
RST: JP2.5, TEENSY3.1.7 (7/RX3)
RST_DAC: DAC.13 (~RST), TEENSY3.1.9 (9/RX2/PWM)
SCK: DAC.10 (SCLK), JP2.3, TEENSY3.1.13 (13/SCK/LED)
SW_B: TEENSY3.1.4 (4/CAN-RX/PWM); also elsewhere on the board
SW_L: TEENSY3.1.23/A9 (23/A9/T/PWM); also elsewhere on the board
SW_R: TEENSY3.1.14/A0 (14/A1); also elsewhere on the board
SW_T: TEENSY3.1.5 (5/PWM); also elsewhere on the board
TR1: TEENSY3.1.0 (0/RX1/T); also elsewhere on the board
TR2: TEENSY3.1.1 (1/TX1/T); also elsewhere on the board
TR3: TEENSY3.1.2; also elsewhere on the board
TR4: TEENSY3.1.3 (3/CAN-TX/PWM); also elsewhere on the board
UNUSED: TEENSY3.1.12 (12/MISO)
VREF_2V5: DAC.3 (VREFH/VREFOUT); also elsewhere on the board

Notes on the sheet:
TEENSY DAC + OLED
OLED HEADER
TEENSY
DAC

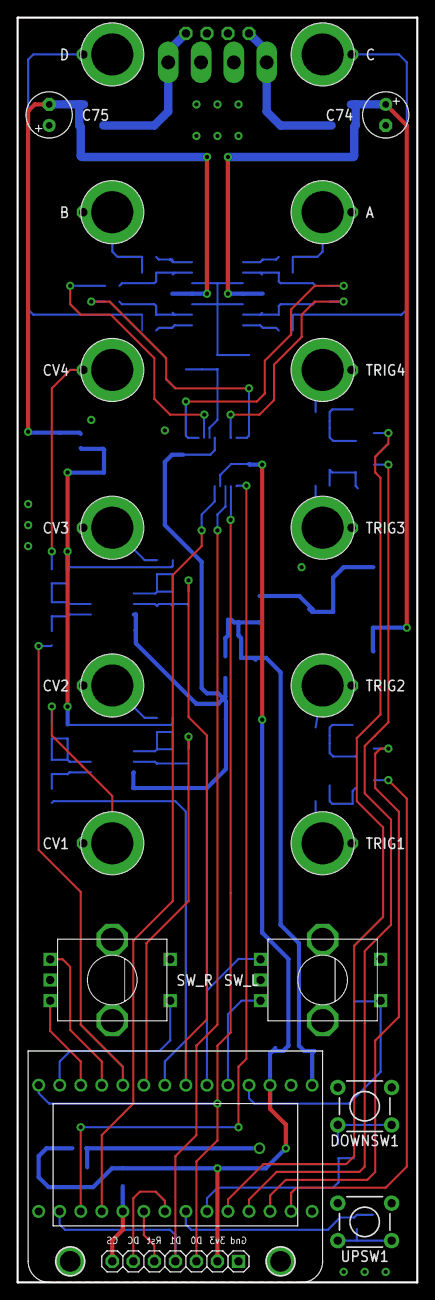
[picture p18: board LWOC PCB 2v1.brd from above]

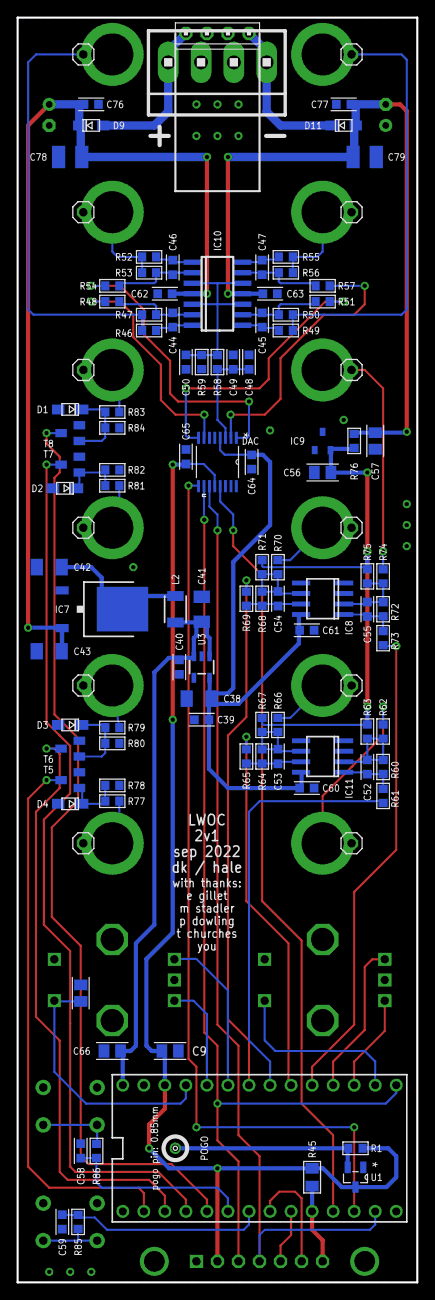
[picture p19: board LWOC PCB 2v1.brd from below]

Board: 2 copper layers, 48.3 x 152.7 mm, 132 parts (111 on the bottom side), 74 nets.

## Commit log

2022-09-08 Add files via upload
    LWOC 2.0 Schematic PDF
2022-09-08 Add files via upload
    LWOC 2.0 sch/brd Eagle files
    [LWOC 2.0.brd, LWOC 2.0.sch]

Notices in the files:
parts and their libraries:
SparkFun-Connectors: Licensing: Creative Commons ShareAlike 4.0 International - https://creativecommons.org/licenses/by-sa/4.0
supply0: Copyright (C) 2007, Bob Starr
